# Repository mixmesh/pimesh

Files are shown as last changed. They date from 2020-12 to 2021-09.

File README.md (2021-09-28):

# PiMesh INFO

## Keyboard

The Pincode is entered via a keypad (sometimes) the suggested
pincodes are typically 4 or 6 digits.

There are 3 prototype keyboards

- one keyboard 3x3 [1-9] on the TCA8418E-EVM (evaluation board)
- one BIG old style (telefon) keypad 4x3  [0-9#\*]
- one MEDIUM style (telefon) keypad 4x3  [0-9#\*]

Pinlayout on EVM board

    C9 C8 C7 C6 C5 C4 C3 C2 C1 C0
    G  V  R7 R6 R5 R4 R3 R2 R1 R0

The BIG keyboard 8-pin layout

    G  C1 C0 R3 C2 R2 R1 R0

For the EVM do not connect the ground (G) pin
(may be used for PULLUP for eached Ri and  Cj)

The SMALL keyboard 7-pin layout

    R2 R1 C0 R0 C2 R3 C1

## LED & PIN-ENTRY

The pin entry process is guided only with LEDS,

Example

- Pin code is needed, RED-BLINK, GREEN-OFF
- Key is pressed FLASH GREEN for each PRESS/RELEASE
- Pin code is accepted GREEN-ON, RED-OFF, device enabled
- When device is enabled a sequence of with # and * will
disable the device again.
- If key presses are delayed too long the current code
will be cleared and the process restarted (no back-off penalty needed?)

Pin code could be accepted either when the correct digits
have been pressed regardless how many key have been pressed.
Or the # key is used to enter the pincode. If keyboard is
missing a key for enter (#) then the first option may be
needed.
Enter a bad pin code will set RED-ON and run a exponetial back-off
delay until a new pin code may be tried.
Pin codes should be digested and matched against a hash.
This way the clear text pin code does not have to be stored in the 
key server.

## LED & BATTERY 

We could use the keyboard (using TCA8418) control 
4 LEDs for the battery level and.
if the SOC (state of charge) is present this could be used
to show the status of the battery level.

## LED & APPLICAION

Also on one LED could be used to show when the application is
running.This is helpful when problem arise in logging in
to the web UI etc. If the application LED is not ON, then there
should not be expected that loggin in would be succesful.

May be some kind of watch dog could try to turn the led OFF.

## Raspberry pi Z pin header 

First part (used part) of the pin header

    3.3v Power  1   2  5v Power
    SDA         3   4  5v Power
    SCL         5   6  GND
    GPIO4(CLK)  7   8  GPIO 14 (Tx)
    GND         9  10  GPIO 15 (Rx)
    GPIO 17    11  12  GPIO 18 (PWM/PCM CLK)
    GPIO 27    13  14  GND
    -          15  16  -
    3.3v Power 17  18  -

## The TCA Lab card colors (temporary)

    1  RED    (3.3v)  TCA
    3  YELLOW (I2C SDA)
    5  GRAY   (I2C SCL)
    7  -                  8 - Tx  (GPS module)
    9  GND               10 - RX  (GPS module)
    11 BROWN  (INT)
    13 WHITE  (RESET)
    15
    17 RED    (3.3v) GPS-module

## The MixMesh mini keyboard (1.3)

	4 - SCL
	6 - SDA
	8 - RESET
	2 - INT
	7 - COL8
	9 - COL9
	5 - PWM
	1 - VCC
	10 - GND
	
## MixMesh keyboard connection to raspberry pi Z

	Keyboard       Raspberry PI Z (pin header)
	--------
	1  - VCC       1    3.3v
	2  - INT       11   (GPIO 17)
	3  - 	       -
	4  - SCL       5    (GPIO 3, I2C SCL)
	5  - PWM       12   (GPIO 18, PWM/PCM CLK)
	6  - SDA       3    (GPIO 2, I2C SDA)
	7  - COL8	   -
	8  - RESET     13   (GPIO 27)
	9  - COL9      -
	10 - GND       9    (GND)

## MixMesh keyboard dimensions

Circuit board thickness 0.95 mm
width: 27.97 mm
height: 46.01 mm

Button height: 1.35mm (pressed) 1.5mm (release)
Platsic cover: 1.4mm?
Height at tca8418: 1.8mm

Plastic cover dimensions (mm)
  Glue frame width: 2
  Width: 2 + 28.47 + 2 = 32.47
  Height: 2 + 46.51 + 2 = 50.51

Led hole radius: 1mm

Component sizes:

	S1,..., S12  radius 3,550      (buttons)
	C1,C2
	R1, ..., R41   w=1.520, h=0.850  (resistors)
	D1, ..., D7    w=0.850, h=1.520  (LED)
	D8             w=3.200, h=1.200  (2-LED)
	IC1            w=3.500, h=3.500  (TCA8418)

	Pin header: w=6.16, h=3.58  (hole in the lid)
	Connector:  w=10.73, h=3.10 (probably not used)
	  pin1  x=11.500, y=15.170
	  pin2  x=11.500, y=13.900
	  pin9  x=16.580, y=15.170
	  pin10 x=16.580, y=13.900

Center point:

	S1   x=6.0  y=34.6
	S2   x=14.0 y=34.6
	S3   x=22.0 y=34.6
	S4   x=6.0  y=26.6
	S5   x=14.0 y=26.6
	S6   x=22.0 y=26.6
	S7   x=6.0  y=18.6
	S8   x=14.0 y=18.6
	S9   x=22.0 y=18.6
	S10  x=6.0  y=10.6
	S11  x=14.0 y=10.6
	S12  x=22.0 y=10.6

	D1   x=4.1 y=41.7
	D2   x=6.7 y=41.7
	D3   x=9.3 y=41.7
	D4   x=11.9 y=41.7
	D5   x=14.5 y=41.7
	D6   x=20.7 y=41.7
	D7   x=23.4 y=41.7
	
	D8   x=6.0  y=4.0

	IC1  x=15.4 y=4.2

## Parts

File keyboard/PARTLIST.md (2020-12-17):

Partlist for Keyboard design

	 U1			TCA8418RTWR
	 
	 R1,R2		4.7k	CRCW06034K70JNEA
	 R3,R4,R22	10k	CRCW060310K0JNEA
	 R5-R12	 	330?	(adopt)
	 R13-R21	10k	CRCW060310K0JNEA
	 
	 C1	 1uF		GRM188R61C105KA93D
	 C2	 0.1uF		GRM155R71C104KA88D

	 D1		BLUE (3%)
 	 D2		BLUE (40%)
	 D3		BLUE (60%)
	 D4	 	BLUE (80%)
	 D5	 	GREEN (100%)
	 D6		GREEN (APP)
 	 D7		YELLOW (COM)

	 D8		GREEN+RED (PIN)

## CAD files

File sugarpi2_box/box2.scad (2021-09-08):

include <MCAD/boxes.scad>;
include <globals.scad>

$fa=1;
$fs=0.4;

collector_hole_width=23;
collector_hole_height=11;
collector_hole_y=box_wall_thickness+box_circuit_padding+
                pizero_first_micro_usb_y;
collector_hole_z=17;

// Box
difference() {
    // Outer box
    translate([box_outer_width/2,box_outer_height/2,
               box_outer_depth/2])
        roundedBox(size=[box_outer_width,box_outer_height,
                         box_outer_depth],
                   radius=box_corner_radius,
                   sidesonly=true);
    // Inner box
    translate([box_inner_width/2+box_wall_thickness,
               box_inner_height/2+box_wall_thickness,
               box_outer_depth/2+box_wall_thickness])
        roundedBox(size=[box_inner_width,box_inner_height,
                         box_inner_depth],
                   radius=box_corner_radius,
                   sidesonly=true);        
    // Connector hole
    translate([box_wall_thickness+box_inner_width-0.001,
               collector_hole_y, collector_hole_z])
        cube([box_wall_thickness*2,collector_hole_width,
              collector_hole_height]); 
}

nut_case_wall_thickness=1;
nut_case_width=box_nut_width+nut_case_wall_thickness*2;
nut_case_height=lid_screw_padding+
                box_nut_width/2;

echo("box_circuit_padding=",box_circuit_padding);
echo("lid_screw_padding=",lid_screw_padding);
echo("nut_case_height",nut_case_height);
echo("box_nut_width/2=", box_nut_width/2);

nut_case_thickness=box_nut_thickness+
                   nut_case_wall_thickness*2;
nut_case_z=16;

// Lower left nut case
nutCase(box_wall_thickness+lid_screw_padding-
        nut_case_width/2,
        box_wall_thickness-0.001,
        nut_case_z, false);
// Lower right nut case
nutCase(box_outer_width-
        (box_wall_thickness+lid_screw_padding+       
         nut_case_width/2),
        box_wall_thickness-0.001,
        nut_case_z, false);
// Upper left nut case
nutCase(box_wall_thickness+lid_screw_padding-
        nut_case_width/2,
        box_outer_height-(box_wall_thickness+nut_case_height)+0.001,
        nut_case_z, true);
// Upper right nut case
nutCase(box_outer_width-
        (box_wall_thickness+lid_screw_padding+       
         nut_case_width/2),
        box_outer_height-(box_wall_thickness+nut_case_height)+0.001,
        nut_case_z, true);

// FIXME: Rewrite. Can be much shorter. Lamer mistakes.
module nutCase(x,y,z,up=true) {
    if(up) {
        difference() {
            union() {
                // Nut case cube
                translate([x,y,z])
                    cube([nut_case_width,nut_case_height,
                          nut_case_thickness]);
                // Nut case support
                translate([x,y,z])
                rotate([0, 90, 0])
                linear_extrude(height=nut_case_width)
                    polygon([[0,0],
                             [0,nut_case_height],
                             [nut_case_thickness, // height
                              nut_case_height]]);
            }
            // Nut case screw
            translate([x+nut_case_width/2,
                       y+box_nut_width/2,
                       z-nut_case_thickness/2])
               cylinder(r=lid_screw_radius,
                        h=nut_case_thickness*2);             
            // Nut case hole
            translate([x+(nut_case_width-box_nut_width)/2,
                         y-0.001,
                       z+(nut_case_thickness-
                          box_nut_thickness)/2])
                cube([box_nut_width,box_nut_width,
                      box_nut_thickness]);           
        }
    } else {
       difference() {
            union() {
                // Nut case cube
                translate([x,y,z])
                    cube([nut_case_width,nut_case_height,
                          nut_case_thickness]);
                // Nut case support
                translate([x+nut_case_width,
                           y+nut_case_height,
                           z])
                rotate([180, 90, 0])
                linear_extrude(height=nut_case_width)
                    polygon([[0,0],
                             [0,nut_case_height],
                             [nut_case_thickness, // height,
                              nut_case_height]]);
            }
            // Nut case screw
            translate([x+nut_case_width/2,
                       y+nut_case_height-box_nut_width/2,
                       z-nut_case_thickness/2])
                cylinder(r=lid_screw_radius,
                         h=nut_case_thickness*2);
            // Nut case hole
            translate([x+(nut_case_width-box_nut_width)/2,
                       y+(nut_case_height-box_nut_width),
                       z+(nut_case_thickness-
                          box_nut_thickness)/2])
               cube([box_nut_width,box_nut_width,
                     box_nut_thickness]);
        }
    }
}

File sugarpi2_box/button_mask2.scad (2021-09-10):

use <MCAD/boxes.scad>
include <globals.scad>

$fa=1;
$fs=0.4;

difference() {
    cube([keyboard_circuit_width,
          keyboard_circuit_height,
          lid_mask_thickness]);
    // Button row 1
    button(button_x0,button_y0);
    button(button_x1,button_y0);
    button(button_x2,button_y0);
    // Button row 2
    button(button_x0,button_y1);
    button(button_x1,button_y1);
    button(button_x2,button_y1);
    // Button row 3
    button(button_x0,button_y2);
    button(button_x1,button_y2);
    button(button_x2,button_y2);
    // Button row 4
    button(button_x0,button_y3);
    button(button_x1,button_y3);
    button(button_x2,button_y3);
    // LED holes
    ledHole(led_d1_x,led_d1_7_y, 1,"circle",-1);
    ledHole(led_d2_x,led_d1_7_y, 1,"circle",-1);
    ledHole(led_d3_x,led_d1_7_y, 1,"circle",4);
    ledHole(led_d4_x,led_d1_7_y, 1,"circle",4);
    ledHole(led_d5_x,led_d1_7_y, 1,"circle",6);
    ledHole(led_d6_x,led_d1_7_y, 1,"circle",6);
    ledHole(led_d7_x,led_d1_7_y, 1, "square");
    ledHole(led_d8_x,led_d8_y, 1.5, "square");
}

module button(x,y) {
    translate([keyboard_circuit_width-x,y,
               -lid_mask_thickness/2])
        cylinder(h=lid_mask_thickness*2,r=button_radius);
}

module ledHole(x,y,radius,type="circle",fn=-1) {
//    translate([keyboard_circuit_width-x,y,
//               -lid_mask_thickness/2])
//        cylinder(h=lid_mask_thickness*2,r=radius);

    if (type == "circle" && fn == -1) {
        translate([keyboard_circuit_width-x,y,
                   -lid_mask_thickness/2])
          linear_extrude(height=lid_mask_thickness*2)
          circle(d=radius*2);
    } else if (type == "circle") {
        translate([keyboard_circuit_width-x,y,
                   -lid_mask_thickness/2])
          linear_extrude(height=lid_mask_thickness*2)
          circle(d=radius*2,$fn=fn);
    } else if(type == "square") {
        translate([keyboard_circuit_width-x,y,
                   -lid_mask_thickness/2])
          linear_extrude(height=lid_mask_thickness*2)
          square(size=radius*2,center=true);
    }
}

// Pillars
pillar_row(lid_slot_height-button_x0/4,
           [true,true,true,true]);
pillar_row(38, [true,true,true,true]);
pillar_row(button_y2+(button_y3-button_y2)/2,
           [true,true,true,true]);
pillar_row(button_y1+(button_y2-button_y1)/2,
           [true,false,true,true]);
pillar_row(button_y0+(button_y1-button_y0)/2,
           [true,false,true,true]);
pillar_row(6.9, [true,false,true,true]);
pillar_row(button_x0/4, [true,true,true,true]);

module pillar_row(y, is_there) {
    if (is_there[0]) {
        pillar(button_x0/4,y);
    }
    if (is_there[1]) {
        pillar(button_x0+(button_x1-button_x0)/2,y);
    }
    if (is_there[2]) {
        pillar(button_x1+(button_x2-button_x1)/2,y);
    }
    if (is_there[3]) {
        pillar(button_x2+(keyboard_circuit_width-button_x2)/
               4*3,y);
    }
}

module pillar(x,y) {
    translate([keyboard_circuit_width-x,y,
               lid_mask_thickness-0.001])
        cylinder(h=lid_mask_pillars_thickness,
                 r=lid_mask_pillars_radius);
}

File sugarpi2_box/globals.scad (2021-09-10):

// PI Zero
pizero_width = 30;
pizero_height = 65;
pizero_screw_padding=3.5;
pizero_first_micro_usb_y=35;

// Keyboard
keyboard_circuit_width=27.97;
keyboard_circuit_height=46.01;
keyboard_circuit_thickness=0.95;
keyboard_pressed_button_thickness=1.35;
keyboard_released_button_thickness=1.5;
keyboard_tca8418_thickness=0.85;
button_radius=3.55;
button_x0=6;
button_x1=14;
button_x2=22;
button_y0=10.6;
button_y1=18.6;
button_y2=26.6;
button_y3=34.6;
led_d1_7_y=41.7;
led_d1_x=4.1;
led_d2_x=6.7;
led_d3_x=9.3;
led_d4_x=11.9;
led_d5_x=14.5;
led_d6_x=20.7;
led_d7_x=23.4;
led_d8_y=4;
led_d8_x=6;

// Box
box_circuit_padding=2;
box_inner_width=pizero_width+box_circuit_padding*2;
box_inner_height=pizero_height+box_circuit_padding*2;
box_inner_depth=30;
box_wall_thickness=1;
box_outer_width=box_inner_width+box_wall_thickness*2;
box_outer_height=box_inner_height+box_wall_thickness*2;
box_outer_depth=box_inner_depth+box_wall_thickness;
box_corner_radius=3;
box_nut_tolerance=0.25;
box_nut_width=5+box_nut_tolerance;
box_nut_thickness=2+box_nut_tolerance;

// Lid
lid_width=box_outer_width;
lid_height=box_outer_height;
lid_mask_thickness=0.5;
lid_mask_pillars_thickness=1.3;
lid_mask_pillars_radius=1;
lid_film_thickness=0.75;
lid_film_glue_frame_width=2;
lid_slot_padding=0.5;
lid_slot_width=keyboard_circuit_width+lid_slot_padding;
lid_slot_height=keyboard_circuit_height+lid_slot_padding;
lid_slot_depth=keyboard_circuit_thickness+
               keyboard_tca8418_thickness+
               lid_mask_pillars_thickness+
               lid_mask_thickness+
               lid_film_thickness;
lid_slot_floor_thickness=0.5;
lid_thickness=lid_slot_floor_thickness+lid_slot_depth;
lid_slot_hole_y=26;
lid_slot_hole_width=14;
lid_slot_hole_height=11;
lid_screw_padding=box_circuit_padding+pizero_screw_padding;
lid_screw_tolerance=0.5;
lid_screw_radius=2.4/2+lid_screw_tolerance;

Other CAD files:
sugarpi2_box/lid2.scad

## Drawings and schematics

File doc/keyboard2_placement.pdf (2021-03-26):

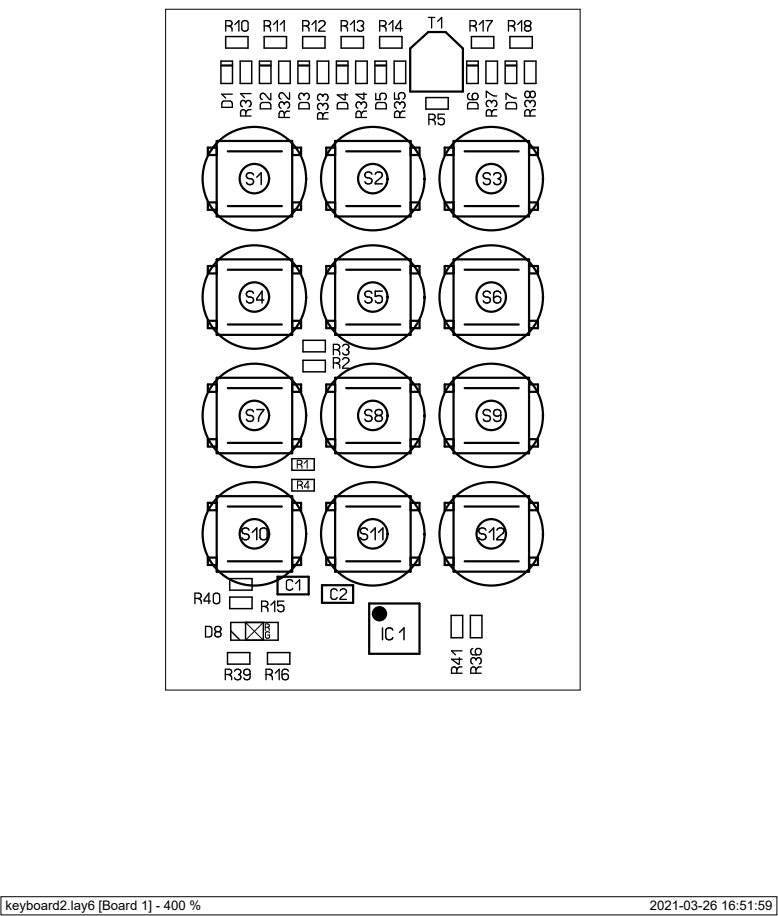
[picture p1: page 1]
keyboard2.lay6 [Board 1] - 400 %

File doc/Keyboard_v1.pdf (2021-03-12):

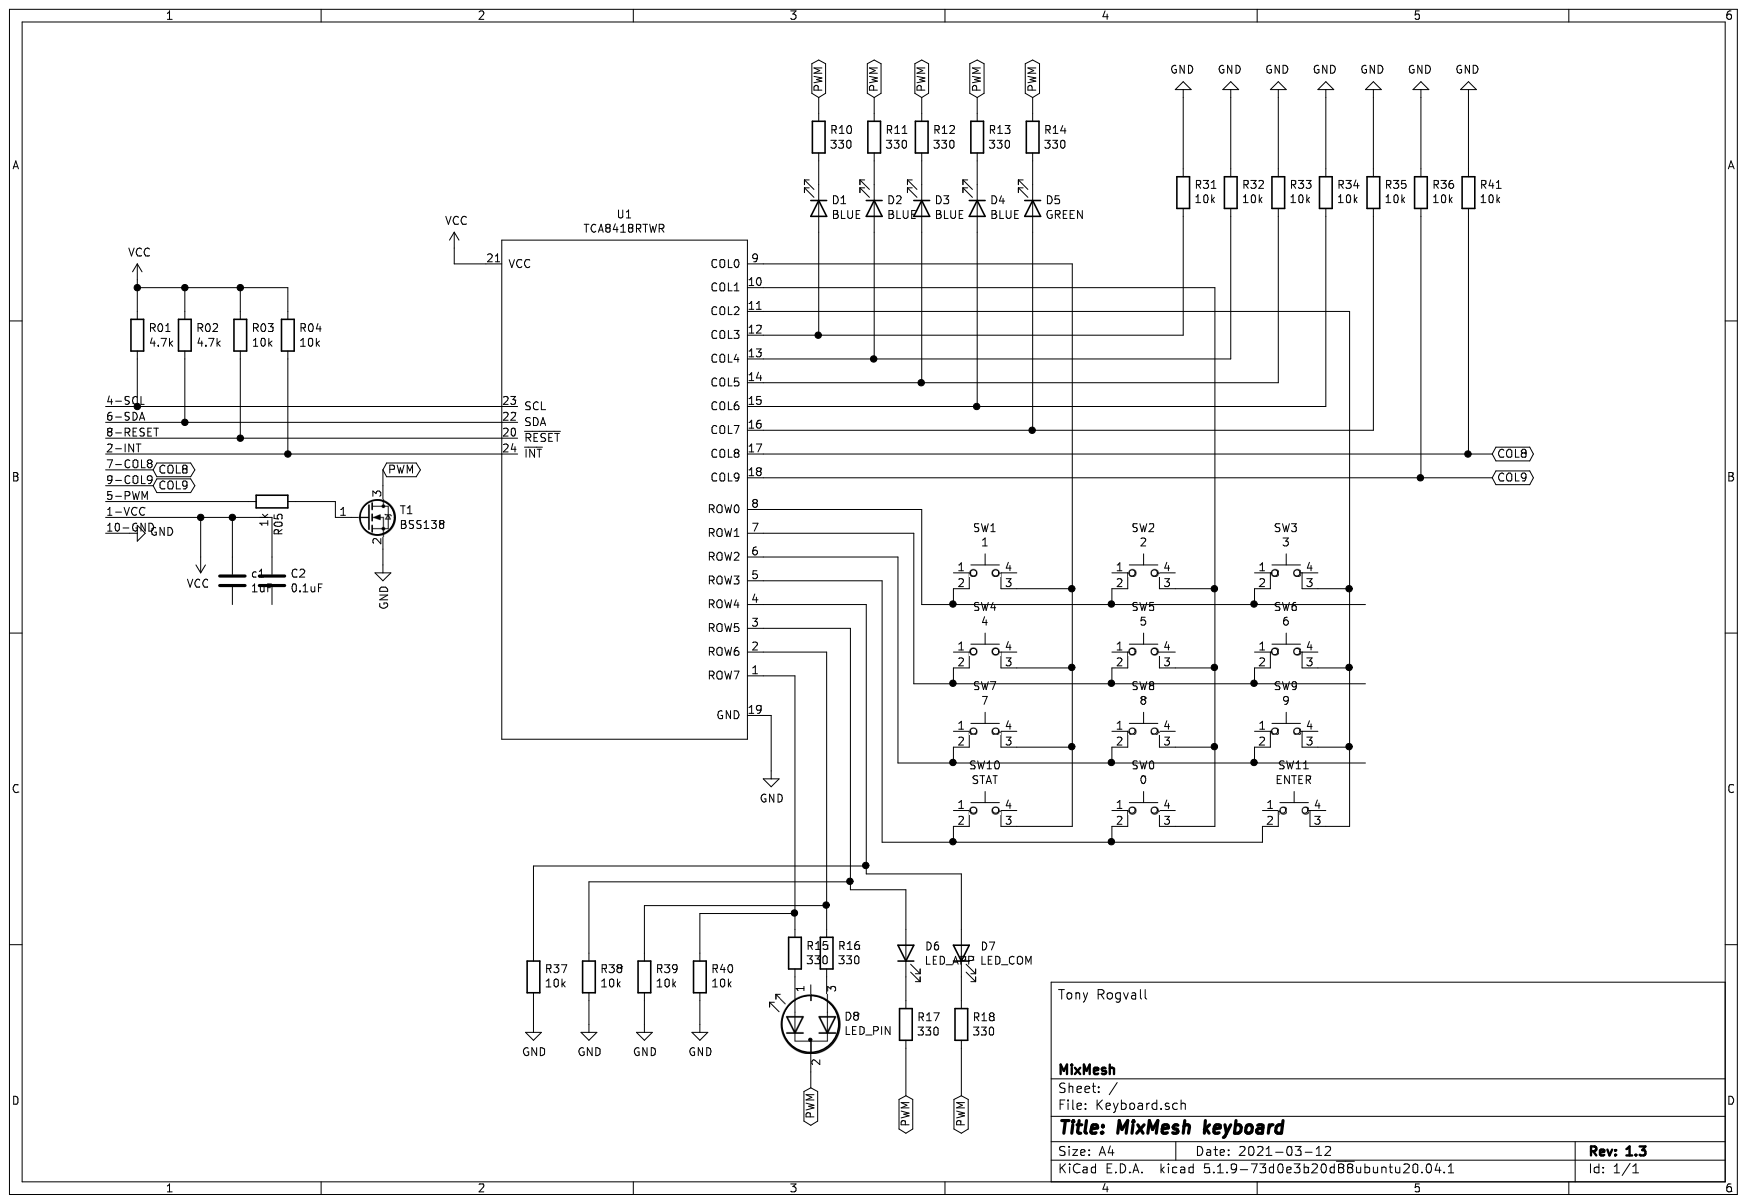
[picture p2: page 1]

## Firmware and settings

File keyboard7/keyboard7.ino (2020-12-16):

int pin_state[14];

//    2   3   4   6
// 7 |1| |4| |7| |*|
// 8 |2| |5| |8| |0|
// 5 |3| |6| |9| |#|
//

// pin -> grid line (+1)
int ver[14] = { 0,0,1,2,3,0,4,0,0,0,0,0,0,0 };
int hor[14] = { 0,0,0,0,0,3,0,1,2,0,0,0,0,0 };

char button[4][3] =
  { { '1', '2', '3' },
    { '4', '5', '6' },
    { '7', '8', '9' },
    { '*', '0', '#' } };

int h;
int v;

void setup() {
  int i;
  Serial.begin (9600);
  while (!Serial) {
    ; // wait for serial port to connect. Needed for native USB port only
  }
  Serial.println ("Keyboard7 started");
  
  for (i = 2; i <= 8; i++) {
    pinMode(i, INPUT);
    pin_state[i] = digitalRead(i);
  }
  h = 0;
  v = 0;
}

void loop() 
{
  int i;

  for (i = 2; i <= 8; i++) {
    int s = digitalRead(i);
    if (s != pin_state[i]) {
      int j;
      pin_state[i] = s;
      if ((j = hor[i]) != 0) h = j;
      else if ((j = ver[i]) != 0) v = j;
      if ((v != 0) && (h != 0)) {
        if (s == LOW)
          Serial.print("PRESS ");
        else 
          Serial.print("RELEASE ");
        Serial.println(button[v-1][h-1]);
        h = v = 0;
      }
    }
  }
}

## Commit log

2020-12-16 stand alone app
    [Keyboard.kicad_pcb, Keyboard.sch]
2020-12-17 depend on i2c and uart
2020-12-17 fixed pin number, added vcc, gnd header
    [Keyboard.sch]
2020-12-30 added PWM to be able to dim all LEDS with one control, each LED is still controlled with an output, added COL9 as GPIO, may be needed
    [Keyboard.sch]
2021-01-01 move COL8-4 to COL7-3, using COL8,COL9 as GPIO, added R4.7k as resistor on MOS gate
    [Keyboard.sch]
2021-01-04 scaled epxmesh demo, moved led names to match real keybaord
    [Keyboard.sch]
2021-01-05 pinephone battery monior
2021-02-07 naming and battery.connected
2021-03-12 updated schema
    [Keyboard.sch]
2021-03-16 com activity timer
2021-03-16 mixmesh.keypad.led for testing
2021-03-17 battery serv for sys/class/power_supply, fixed epxmesh to mimic pimesh as close as possble
2021-03-25 connector position
2021-03-26 added pin header dimensions
2021-03-26 circuit placement info
2021-09-02 added scad files for sugarpi2 box
    [box2.scad, button_mask2.scad, globals.scad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]
2021-09-02 added glue frame for keyboard film
    [globals.scad, lid2.scad]
2021-09-03 fine tuned netcases and fixed a bug
    [box2.scad, globals.scad]
2021-09-09 better button mask with led holes
    [button_mask2.scad, globals.scad, lid2.scad]
2021-09-28 tried a hole layer, fixed distances
